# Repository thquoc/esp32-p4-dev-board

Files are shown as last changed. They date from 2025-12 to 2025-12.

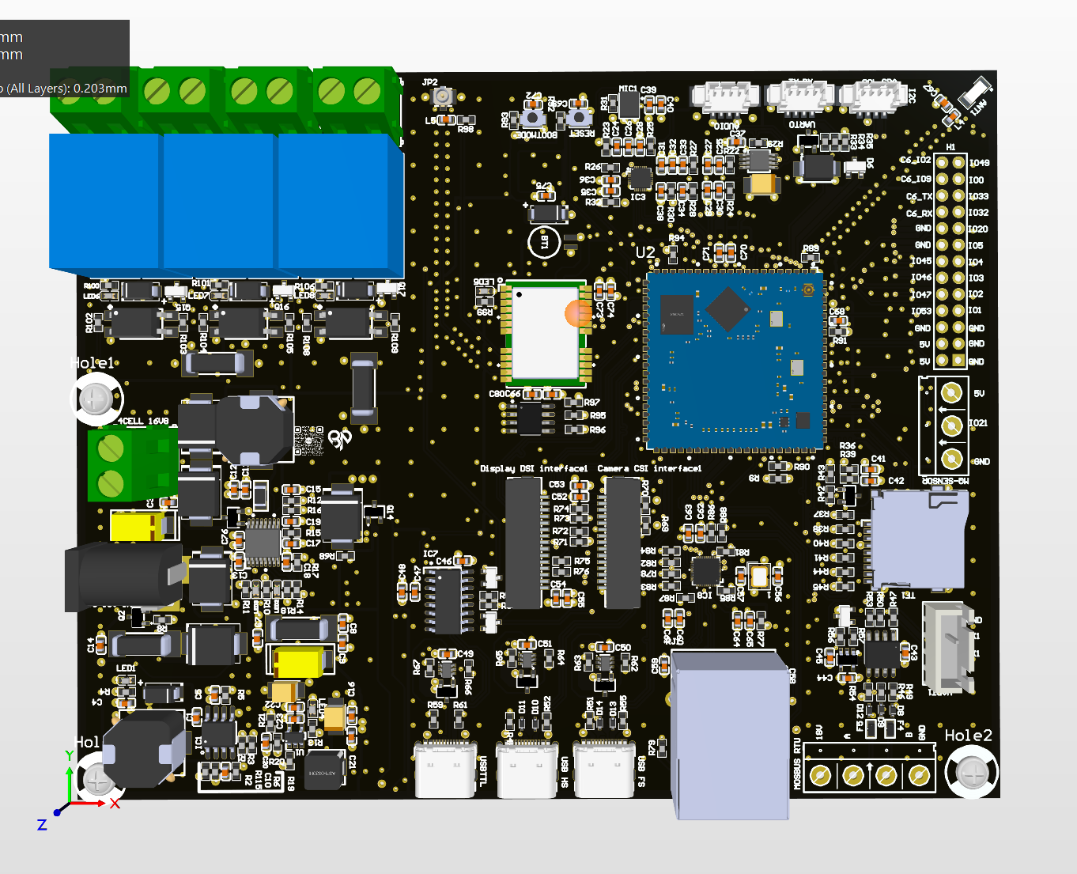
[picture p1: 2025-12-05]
3D-VIEW.png

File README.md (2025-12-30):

#CHỌN MẠCH CHUYỂN NGUỒN CHO USB.
-
#1. Mạch nguồn ưu tiên sử dụng diode.
-  
-  Mạch nguồn ưu tiên sử dụng diode hoạt động dựa trên nguyên lý so sánh điện áp, tự động chọn nguồn có điện áp cao hơn để cấp cho tải. Mạch này thường ứng dụng để chuyển đổi nguồn pin và sạc.


-  Khi chúng ta cấp nguồn PIN(4V2) vào anode của diode D20, thì có sự chênh lệch điện áp giữa anode và cathode của diode này, nên diode D20 sẽ phân cực thuận. Khi đó V_LOAD = 3V7.
-  Đến khi có sạc usb được cấp vào thì ngay lập tức D21 sẽ được phân cực thuận(5-3,7>0.5V). Khi đó V_LOAD = 4V5. Lúc này diode D20 sẽ xảy ra hiện tượng phân cực ngược vì điện áp chân cathode cao hơn điện áp chân anode, đẩy D20 vào trạng thái phân cực ngược và đóng hoàn toàn. Nhờ đó, nguồn USB sẽ thay thế PIN cấp nguồn cho tải và chặn dòng ngược về phía PIN.
-  Ưu điểm: chuyển mạch nhanh, chi phí thấp, chặn dòng ngược.
-  Nhược điểm: sụt áp, công suất thấp.

#2. Mạch chuyển nguồn dùng "ideal diode".
-  
-  Mạch này vẫn hoạt động dựa trên nguyên lý so sánh điện áp, tự động chọn nguồn có điện áp cao hơn để cấp cho tải. Tuy nhiên, mạch này rất "nhạy" áp, khi có sự chênh lệch nhỏ chỉ 0.01V thôi thì mạch đã chuyển nguồn rồi.


-  Trường hợp USB1_5V > USB_5V: Trong trường hợp này transistor pnp bên phải của Q11 và điện trở 51k sẽ kéo chân Gate của p-mosfet về mức điện áp thấp hơn điện áp USB_5V, lúc này p-mosfet dẫn(Vg < Vs).
-  Trường hợp USB1_5V < USB_5V:Trường hợp này transistor pnp bên phải của Q11 kéo chân Gate của p-mosfet Q8 lên mức điện áp xấp xỉ mức điện áp USB_5V, lúc này p-mosfet đóng(Vg ~Vs).
-  Ưu điểm: chuyển mạch nhanh, không sụt áp, công suất cao, chặn dòng ngược.
-  Nhược điểm: chi phí cao hơn diode, phụ thuộc vào sai số linh kiện, không kiểm soát được nguồn nào sẽ là nguồn ưu tiên.
Các nguồn có giá trị điện áp bằng nhau, trong thực tế các nguồn này không bằng nhau tuyệt đối vì chúng còn phụ thuộc vào sai số linh kiện, sụt áp tải dòng... Chính nhờ đặc điểm này nên tôi có thể dùng nguồn ưu tiên "ideal diode" để chuyển mạch cho các nguồn USB. Vậy tại sao tôi không dùng nguồn ưu tiên sử dụng diode?
  -  Mạch nguồn ưu tiên diode gây sụp áp lớn khoảng 0.5V, và điện áp logic của cổng usb laptop/pc thường hoạt động trong khoảng ~(4.75 đến 5V). Chính vì thế khi sử dụng mạch nguồn ưu tiên diode sẽ dẫn đến lỗi "không nhận diện được USB".

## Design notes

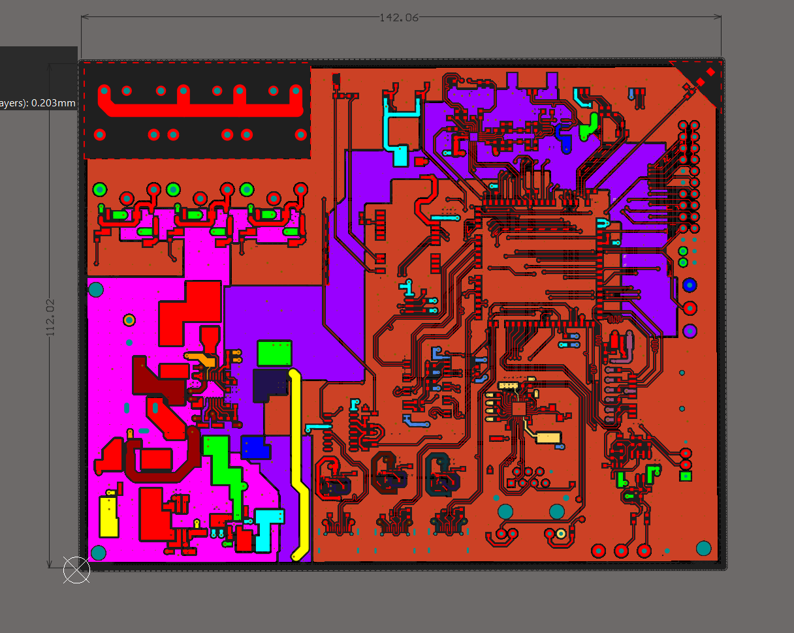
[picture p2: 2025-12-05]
L1-TOP.png

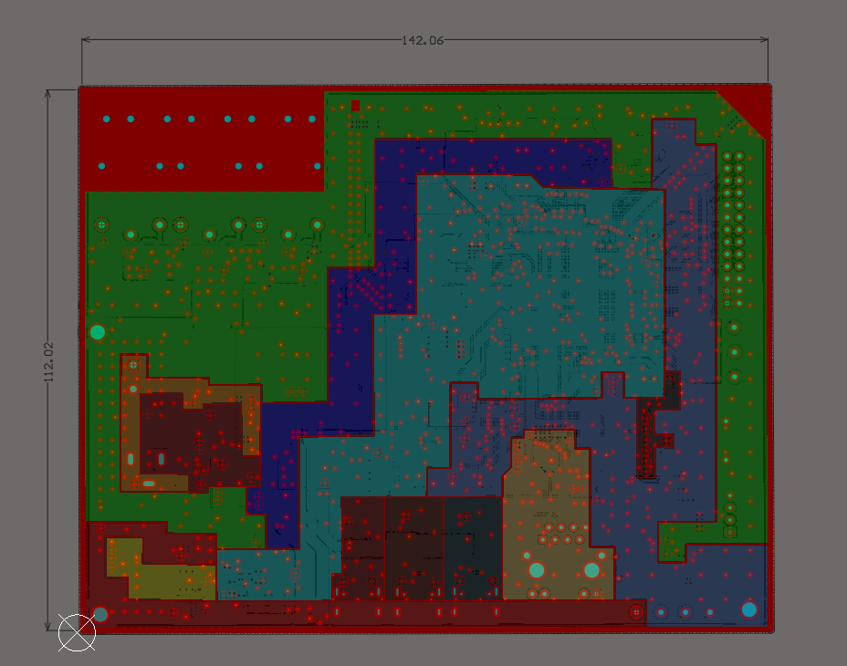
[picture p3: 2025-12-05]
L3-PW.png

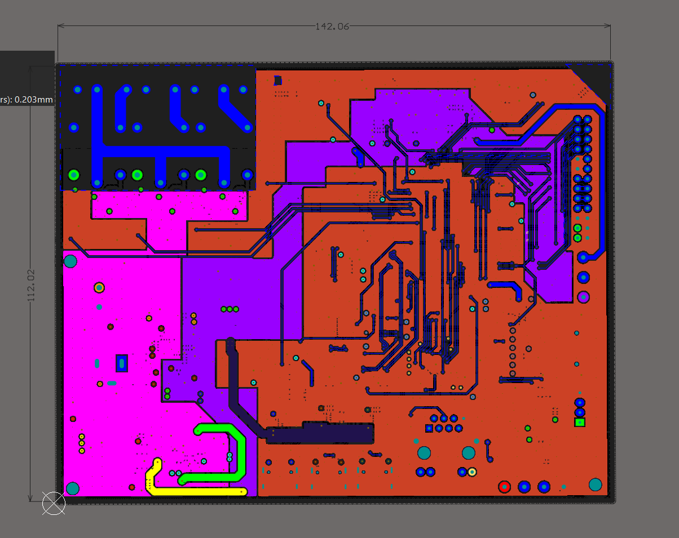
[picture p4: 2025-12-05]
L4-BOT.png

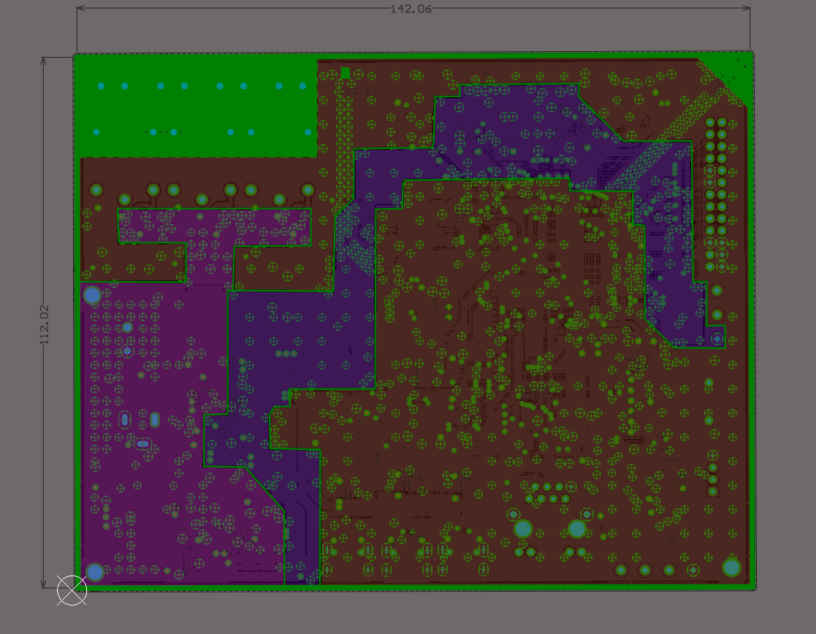
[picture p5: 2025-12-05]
L2-GND.png

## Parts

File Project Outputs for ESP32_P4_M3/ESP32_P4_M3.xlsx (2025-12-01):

Comment | Description | Designator | Footprint | LibRef | Quantity
25MHz |  | 1 | CRYSTAL-SMD_4P-L3.2-W2.5-BL | X322525MOB4SI | 1
RF ANT 2450MHz CERAMIC SMD | Ceramic Antenna 5.19dBi 100MHz 2.45GHz 1206 RF Antennas RoHS | ANT1 | ANT-SMD-2_L3.2-W1.6-C504002 | kinghelm KH-3216-A35 | 1
BATTERY CLIP COIN CR2032 SMD | Battery Clip CR2032 SMD Blade Type Power Connector Assemblies RoHS | BT1 | BATTERY | C70373 | 1
100nF | 50V 100nF X7R ±10% 0603 Ceramic Capacitors ROHS | C1, C12, C13, C17, C21, C23, C25, C30, C35, C39, C42, C43, C44, C45, C46, C48, C52, C54, C58, C59, C61, C63, C65, C66, C69, C72, C73 | C0603 | CC0603KRX7R9BB104 | 27
22uF Tantalum | CAP TANT 22uF ±10% 50V CASE-X-7343-43(mm) | C2, C6 | CAP-SMD_L7.3-W4.3-R-RD | T491X226K050AT | 2
10uF | 25V 10uF X5R ±20% 0603 Ceramic Capacitors ROHS, 10V 10uF X5R ±10% 0603 Ceramic Capacitors ROHS | C3, C5, C7, C9, C11, C16, C22, C36, C40, C41, C47, C53, C55, C60, C62, C64, C74, C76, C80 | C0603 | CL10A106MA8NRNC, CL10A106KP8NNNC | 19
22uF | 10V 22uF X5R ±20% 0603 Ceramic Capacitors ROHS | C4 | C0603 | CL10A226MP8NUNE | 1
1uF | 25V 1uF X7R ±10% 0603 Ceramic Capacitors ROHS | C8, C14, C24, C26, C28, C31, C32, C33, C34, C37, C38, C49, C50, C51, C68, C75 | C0603 | CL10B105KA8NNNC | 16
150PF | 50V 150pF NP0 ±5% 0603 Ceramic Capacitors ROHS | C10 | C0603 | CC0603JRNPO9BN151 | 1
1.3pf | 50V 1.3pF NP0 0603 Ceramic Capacitors ROHS | C15 | C0603 | CC0603CRNPO9BN1R3 | 1
470pF | 50V 470pF C0G ±5% 0603 Ceramic Capacitors ROHS | C18 | C0603 | CL10C471JB8NNNC | 1
220nF | 50V 220nF X7R ±10% 0603 Ceramic Capacitors ROHS | C19 | C0603 | CL10B224KB8NNNC | 1
22pf | 50V 22pF C0G ±5% 0603 Ceramic Capacitors RoHS | C20, C27, C29, C56, C57, C70, C71 | C0603 | CL10C220JB8NNNC | 7
1pF/NC | 50V 1pF C0G 0603 Ceramic Capacitors RoHS | C67 | C0603 | FCC0603N1R0C500CT | 1
100uF | 100uF 10V ±10% CASE-B-3528-19(mm) Tantalum Capacitors RoHS | C77, C78, C79 | CAP-SMD_L3.5-W2.8-R-RD | CA45A-B-10V-100UF-K | 3
CONN FFC FPC 15POS 1mm BOTTOM CNT SMD R/A | -25℃~+85℃ Hinged Lid 15P 1mm 500mA 50V Bottom Contact Surface Mount, Right Angle SMD,P=1mm,Surface Mount,Right Angle FFC, FPC (Flat Flexible) Connector Assemblies RoHS | Camera CSI interface1, Display DSI interface1 | FPC-SMD_15P-P1.00_XUNPU_FPC-1.0FX-15PWCR-H20 | FPC-1.0FX-15PWCR-H20 | 2
533980471 | 4P PicoBlade(MX 1.25) 1x4P Tin -40℃~+105℃ White 1.25mm 125V 4 1A 1 Surface Mount,Vertical SMD,P=1.25mm Headers, Male Pins RoHS | CN1, CN2, CN3 | CONN-SMD_4P-P1.25_XUNPU_WAFER-GH1.25-4PWB | 533980471 | 3
TERM BLK 2POS 5mm TH | 2.5 1x2P 12~22 Green 24A -40℃~+105℃ 250V Through Hole 5mm 1 2 Through Hole,P=5mm Wire to Board RoHS | CONN1, CONN2, CONN3, CONN4, CONN5 | CONN-TH_P5.00_KF128-5.0-2P | KF128-5.0-2P | 5
SMA(DO-214AC) | 80A 40V 500mV@3A 3A SMA(DO-214AC) Single Diodes ROHS | D1, D16, D17, D18, D19 | SMA_L4.4-W2.6-LS5.0-RD | B340A-13-F | 5
B540CQ-13-F | 40V 550mV@5A 5A SMC(DO-214AB) Single Diodes ROHS | D2, D3, D4, D5, D15 | SMC_L6.9-W5.9-LS7.9-RD | B540CQ-13-F | 5
DIODE ARR SCHOTTKY 30V SOT-23 | 600mA 30V 1 Pair Common Cathode 1V@100mA 200mA SOT-23 Single Diodes RoHS | D6 | SOT-23-3_L2.9-W1.3-P1.90-LS2.4-BR | BAT54C_C916424 | 1
TVS DIODE 5VWM 9.2VC DO-214AA | 65.3A 600W 9.2V 6.4V Bidirectional 5V DO-214AA TVS Diodes RoHS | D7 | SMB_L4.6-W3.6-LS5.3-BI | SMBJ5.0CA_C83323 | 1
TVS DIODE 5VWM 18.6VC SOD-523 | 9.4A@8/20us 18.6V 7.8V 5V SOD-523 TVS Diodes RoHS | D8, D9, D10, D11, D12, D13, D14 | SOD-523_L1.2-W0.8-LS1.6-BI | LESD5D5.0CT1G | 7
10A | 4mΩ 100Ω@100MHz SMD,8.5x3.1mm Ferrite Beads and Chips ROHS | F1, F2, F3, F6 | IND-SMD_L8.5-W3.1 | HI3312X101R-10 | 4
PTC RESET FUSE 24V 100mA 0603 | 24V 100mA 40A 300mA 900mΩ 0603 PTC Resettable Fuses RoHS | F4, F5 | F0603 | 0603-010-24V | 2
13X2 | 26P 2x13P Gold Copper Alloy -40℃~+105℃ Pin Header Black 2.54mm 2.5mm 6mm 1kV 3mm 3A 2 Through Hole 2.54mm Through Hole,P=2.54mm Headers, Male Pins RoHS | H1 | HDR-TH_26P-P2.54-V-M-R2-C13-S2.54 | HX PZ2.54-2X13P ZZ | 1
Header 4 | Header 4 (Green) | HD1 | HED4 | Hed4 | 1
Pad Big | Pad Big | Hole1, Hole2, Hole3, Hole4 | Screw 3.0 | Pad_Big | 4
MP1584EN-LF | Buck Switching Regulator IC | IC1 | SOIC-8_L4.9-W3.9-P1.27-LS6.0-BL-EP3.3 | MP1584EN-LF | 1
5A TSSOP-16 Battery Management ROHS | Multi-type battery charging management integrated circuit with maximum power point tracking function for solar cells | IC2 | TSSOP-16_L5.0-W4.4-P0.65-LS6.4-BL | CN3722 | 1
Low Power Mono Audio CODEC | 1.8V~3.3V QFN-20-EP(3x3) Signal Switches, Multiplexers, Decoders RoHS | IC3 | WQFN-20_L3.0-W3.0-P0.40-BL-EP1.7 | ES8311 | 1
NS4150B 3.0W Mono Class-D Audio Power Amplifier | 4mA 1-Channel 3Wx1@4Ω Class D MSOP-8 Audio Amplifiers RoHS | IC4 | MSOP-8_L3.0-W3.0-P0.65-LS5.0-BL | NS4150 | 1
Low-Power, Slew-Rate-Limited RS-485/RS-422 Transceivers | Transceiver 4.75V~5.25V SOIC-8 Drivers, Receivers, Transceivers RoHS | IC5 | SOP-8_L4.9-W3.9-P1.27-LS6.0-BL | MAX485ESA+T_C41365333 | 1
SINGLE 2-INPUT NAND GATE WITH SCHMITT-TRIGGER INPUTS | 5ns@5V,50pF 10uA 1.65V~5.5V NAND Gate SOT-23-5 Gates and Inverters RoHS | IC6 | SOT-23-5_L3.0-W1.7-P0.95-LS2.8-BL | TP74LVC1G132S5 | 1
CH340 | Transceiver USB 2.0 SOP-16 Interface Controllers RoHS | IC7 | SOP-16_L10.0-W3.9-P1.27-LS6.0-BL | CH340C | 1
Single Port Fast Ethernet Transceiver | Ethernet Transceiver 3.3V QFN-32-EP(4x4) Drivers, Receivers, Transceivers RoHS | IC8 | QFN-32_L4.0-W4.0-P0.40-BL-EP2.7 | IP101GRI | 1
256 kb Serial CMOS EEPROM with I2C Protocol | 256Kbit 1.8V~5.5V 1MHz I2C SOIC-8 Memory (ICs) RoHS | IC9 | SOIC-8_L4.9-W3.9-P1.27-LS6.0-BL | CAT24C256WI-GT3 | 1
GPS NEO 6 | GPS Development Tools SparkFun GNSS-RTK Dead Reckoning Breakout - ZED-F9K (Qwiic) | IC10 | XCVR_NEO-6M-GPS | NEO-6M-GPS | 1
PC817X2CSP9F | 50mA 200mV@20mA,1mA 80V 6V DC SMD-4P Transistor, Photovoltaic Output Optoisolators RoHS | IC11, IC12, IC13 | smd pc817 | PC817X2CSP9F | 3
Jac DC | Jac DC input | JDC1 | DC-IN | DCIN | 1
CONN RCPT IPEX 50Ω SMD | 1 Male Pin IPEX Board Side 1.25mm -40℃~+90℃ 6GHz 50Ω 2mm SMD Coaxial Connector (RF) Assemblies RoHS | JP2 | RF-SMD_FRF05002-JSS103M | U.FL-R-SMT-1(80) | 1
15uH | 3.4A 15uH Magnetic Shielded Inductor ±20% 41mΩ SMD,10.1x10.1mm Fixed Inductors ROHS | L1, L2 | IND-SMD_L10.1-W10.0 | YDRH105R-150M | 2
2.2uH | 7A 2.2uH Molded Inductor ±20% 7A 29mΩ SMD,5.4x5.2mm Fixed Inductors RoHS | L3 | IND-SMD_L5.4-W5.2 | APH0530T2R2M | 1
2.2nH | 700mA 2.2nH ±5% Wirewound Chip Inductor 80mΩ 0603 Fixed Inductors RoHS | L4 | C0603 | MQG06HF2N2JT7 | 1
22nH | 300mA 22nH ±5% 600mΩ 0603 Fixed Inductors RoHS | L5 | C0603 | VHF160808H22NJT | 1
XL-1608SURC-06 | 20mA 2.3V Red 50mW 0603 LED Indication - Discrete ROHS | LED1, LED4, LED5, LED6, LED7, LED8 | LED0603-RD_RED | XL-1608SURC-06 | 6
Green | 5mA 500mcd 526nm~532nm Green 70mW 2.8V 0603 LED Indication - Discrete ROHS | LED2 | LED0603-RD_RED | D-060306G1/SS2/G1 | 1
RED | 20mA 2.3V Red 50mW 0603 LED Indication - Discrete ROHS | LED3 | LED0603-RD_RED | XL-1608SURC-06 | 1
MSM381A3729H9CP | OCLGA-4(3x3.8) MEMS Microphones ROHS | MIC1 | MIC-SMD_4P-L3.8-W3.0-P2.46-S1.70-TR | MSM381A3729H9CP | 1
Header 3 | Header 3 (Green) | MQ-1 | HED3 | Hed3 | 1
MOSFET P-CH 30V 4.3A SOT-23 | 30V 4.3A 48mΩ@10V 2.5V@250uA 1 P-Channel SOT-23 Single FETs, MOSFETs ROHS | Q1, Q2, Q3, Q4, Q8, Q9, Q10, Q14 | SOT-23-3_L2.9-W1.6-P1.90-LS2.8-BR | AO3407A | 8
TRANS PNP 25V 1.5A SOT-23 | 300mW 25V 1.5A PNP SOT-23 Single Bipolar Transistors RoHS | Q5 | SOT-23-3_L2.9-W1.3-P1.90-LS2.4-BR | SS8550_C7420371 | 1
TRANS NPN 25V 0.5A SOT-23 | 300mW 25V 500mA NPN SOT-23 Single Bipolar Transistors RoHS | Q6, Q7 | SOT-23-3_L2.9-W1.3-P1.90-LS2.4-BR | S8050_C2828466 | 2
TRANS PNP 40V 200mA SOT-363 | 40V 150mW 200mA PNP SOT-363 Single Bipolar Transistors RoHS | Q11, Q12, Q13 | SC-70-6_L2.2-W1.3-P0.65-LS2.1-TL | LMBT3906DW1T1 | 3
TRANS NPN 50V 150mA SOT-23 | 200mW 50V 150mA NPN SOT-23 Single Bipolar Transistors RoHS | Q15, Q16, Q17 | SOT-23-3_L2.9-W1.3-P1.90-LS2.4-BR | 2SC1815 | 3
210KΩ | 100mW 210kΩ 75V ±100ppm/℃ Thick Film Resistor ±1% 0603 Chip Resistor - Surface Mount ROHS | R1 | R0603 | 0603WAF2103T5E | 1
100kΩ | 100mW 100kΩ 75V ±100ppm/℃ Thick Film Resistor ±1% 0603 Chip Resistor - Surface Mount ROHS | R2, R5, R6, R20 | R0603 | RC0603FR-07100KL | 4
40.2KΩ | 40.2kΩ 100mW 75V ±25ppm/℃ Thin Film Resistor ±0.1% 0603 Chip Resistor - Surface Mount ROHS | R3 | R0603 | RT0603BRD0740K2L | 1
1kΩ | 100mW 1kΩ 50V ±100ppm/℃ Thick Film Resistor ±5% 0603 Chip Resistor - Surface Mount ROHS | R4, R13, R35, R79, R80, R95, R96, R99, R100, R101, R106 | R0603 | RMC 0603 1K J N | 11
91mΩ | 250mW 91mΩ 500V ±600ppm/℃ Thick Film Resistor ±1% 1206 Chip Resistor - Surface Mount ROHS | R7 | R1206 | FRL1206FR091TS | 1
10kΩ | 100mW 10kΩ 75V ±100ppm/℃ Thick Film Resistor ±1% 0603 Chip Resistor - Surface Mount ROHS | R8, R16, R18, R19, R23, R29, R42, R43, R46, R54, R58, R60, R62, R64, R66, R68, R69, R70, R90, R91, R92, R93, R97, R103, R105, R109 | R0603 | RC0603FR-0710KL | 26
0Ω | 100mW 0Ω 75V Thick Film Resistor ±5% 0603 Chip Resistor - Surface Mount RoHS | R9, R25, R27, R28, R30, R31, R32, R33, R34, R36, R39, R47, R50, R53, R72, R74, R75, R76, R77, R89 | R0603 | RC0603JR-070RL | 20
4.7kΩ | 100mW 4.7kΩ 75V ±100ppm/℃ Thick Film Resistor ±1% 0603 Chip Resistor - Surface Mount ROHS | R10, R11 | R0603 | RC0603FR-074K7L | 2
59KΩ | 100mW 59kΩ 75V ±100ppm/℃ Thick Film Resistor ±1% 0603 Chip Resistor - Surface Mount ROHS | R12 | R0603 | FRC0603F5902TS | 1
18.7kΩ | 100mW 18.7kΩ 75V ±100ppm/℃ Thick Film Resistor ±1% 0603 Chip Resistor - Surface Mount ROHS | R14 | R0603 | FRC0603F1872TS | 1
120Ω | 100mW 120Ω 75V ±100ppm/℃ Thick Film Resistor ±1% 0603 Chip Resistor - Surface Mount ROHS | R15 | R0603 | 0603WAF1200T5E | 1
1.3KΩ | 100mW 1.3kΩ 75V ±25ppm/℃ Thin Film Resistor ±0.1% 0603 Chip Resistor - Surface Mount ROHS | R17 | R0603 | RT0603BRD071K3L | 1
22kΩ | 100mW 22kΩ 75V ±100ppm/℃ Thick Film Resistor ±1% 0603 Chip Resistor - Surface Mount RoHS | R21, R22, R24 | R0603 | RC0603FR-0722KL | 3
100Ω | 100mW 100Ω 75V ±100ppm/℃ Thick Film Resistor ±1% 0603 Chip Resistor - Surface Mount ROHS | R26 | R0603 | RC0603FR-07100RL | 1
5.1KΩ | 100mW 5.1kΩ 75V ±100ppm/℃ Thick Film Resistor ±1% 0603 Chip Resistor - Surface Mount RoHS | R37, R38, R40, R41, R44, R45, R48, R49, R51, R52, R55, R59, R61, R81, R82, R83, R84, R85, R86, R88, R94 | R0603 | FRC0603F5101TS | 21
2k2Ω | 100mW 2.2kΩ 75V ±100ppm/℃ Thick Film Resistor ±1% 0603 Chip Resistor - Surface Mount RoHS | R56, R57, R71, R73 | R0603 | RC0603FR-072K2L | 4
51kΩ | 100mW 51kΩ 75V ±100ppm/℃ Thick Film Resistor ±1% 0603 Chip Resistor - Surface Mount RoHS | R63, R65, R67 | R0603 | RC0603FR-07100KL_1RC0603FR-0751KL | 3
1.5kΩ | 100mW 1.5kΩ 75V ±100ppm/℃ Thick Film Resistor ±1% 0603 Chip Resistor - Surface Mount RoHS | R78 | R0603 | RC0603FR-071K5L | 1
6.19KΩ | 6.19kΩ 100mW 75V ±100ppm/℃ Thick Film Resistor ±1% 0603 Chip Resistor - Surface Mount RoHS | R87 | R0603 | AC0603FR-076K19L | 1
50Ω | 100mW 50Ω 75V ±50ppm/℃ Thin Film Resistor ±0.1% 0603 Chip Resistor - Surface Mount ROHS | R98 | R0603 | RT0603BRE0750RL | 1
220Ω | 100mW 220Ω 75V ±100ppm/℃ Thick Film Resistor ±1% 0603 Chip Resistor - Surface Mount RoHS | R102, R104, R108 | R0603 | RC0603FR-07220RL | 3
24.9kΩ | 1100mW 24.9kΩ 75V ±100ppm/℃ Thick Film Resistor ±1% 0603 Chip Resistor - Surface Mount ROHS | R115 | R0603 | 0603WAF2492T5E | 1
CONN MOD JACK RJ45 TH | 1 With LED Through Hole Modular/Ethernet Connector Jacks With Magnetics RoHS | RJ1 | RJ45-TH_HR913550A | HR913550A | 1
Relay 15A/5V | Relay SPDT,10A - 5VDC 5 Pin | RL1, RL2, RL3 | RL-5V-15A | SRD-05VDC-SL-C | 3
B3U-1000P | 12V 2.5mm Round Button 3mm SPST 50mA SMD,3x2.5mm Tactile Switches ROHS | SW1, SW2 | KEY-SMD_B3U-1000PM | B3U-1000P | 2
CONN MICRO SD CARD (TF CARD) SMD | -25℃~+85℃ Push-Push 2mm Connector and Ejector MicroSD Card (TF Card) SMD PC Card Sockets RoHS | TF1 | TF-SMD_SH_SH-TF-01A | SH-TF-01A | 1
TLV62569DBVR | 1.5MHz 2A Buck Adjustable 600mV~5.5V 1 SOT-23-5 Voltage Regulators - DC DC Switching Regulators RoHS | U1 | SOT-23-5_L3.0-W1.7-P0.95-LS2.8-BR | TLV62569DBVR | 1
ESP32P4_QFN104 |  | U2 | JC-ESP32P4-M3_V0.2 | JC-ESP32P4-M3 | 1
TYPE C 2.0 | USB 2.0 1 16P -40℃~+85℃ Type-C SMD USB, DVI, HDMI Connector Assemblies RoHS | USB1, USB2, USB3 | USB-C-SMD_G-SWITCH_GT-USB-7010ASV | GT-USB-7010ASV | 3
JP4 | Connector 4 | ZJP1 | CON4 | Con4 | 1

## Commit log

2025-12-18 fix SD card error
    [ESP32_P4_M3.PrjPcb, ETH-PHY.SchDoc, MICROSD CARD.SchDoc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]
2025-12-30 fix solution
    [Power.SchDoc, RELAY.SchDoc, USB.SchDoc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]
